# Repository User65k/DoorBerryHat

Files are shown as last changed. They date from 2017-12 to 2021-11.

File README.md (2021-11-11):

# DoorBerry
Use a Raspberry Pi as a VoIP door intercom system.

I use it with my FritzBox to alert all my DECT Phones.
Tested on a Pi 2B+ and a Pi Zero with raspbian (and mono).

## Software

Please find it [here](https://github.com/User65k/DoorBerryServer).

## Hardware

All Files are creaded with [KiCad](http://kicad.org/).

### Old Door system

The new System replaces the indoor part of a RITTO intercom system. The Door itself and the other appartments where not modified.

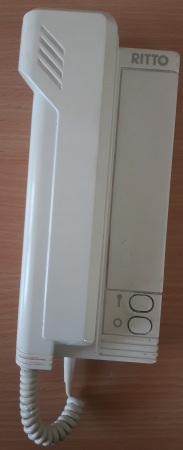
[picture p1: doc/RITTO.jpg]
RITO Door bell


The old system had a fairly simple circut:

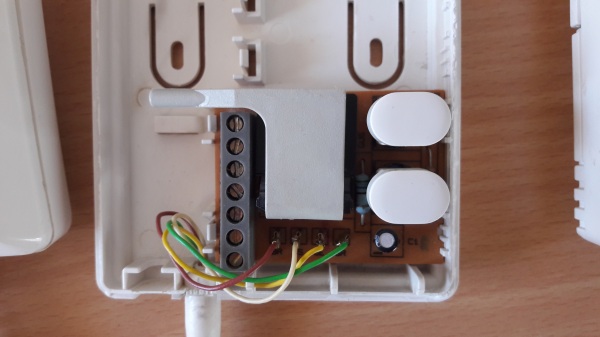
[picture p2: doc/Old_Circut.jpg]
RITO Inside


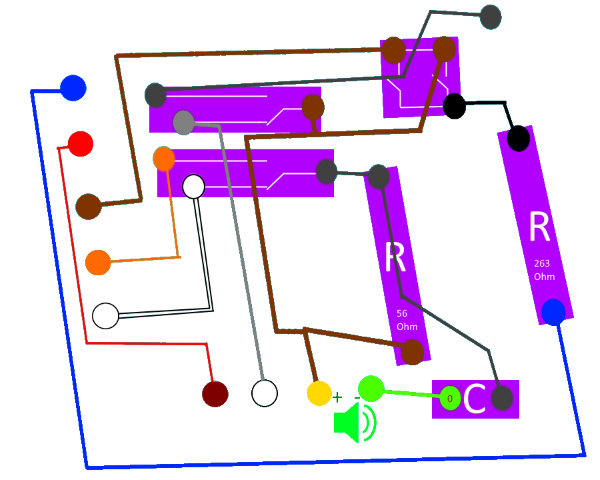
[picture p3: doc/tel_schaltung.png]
Circut


### New Door Intercom

The system is replaced by a Raspberry with a custum Hat (utilizing the GPIOs of the Pi).
Bell and Buzzer can operate independently from the new system (in case of Network errors, Bugs, :speak_no_evil:).

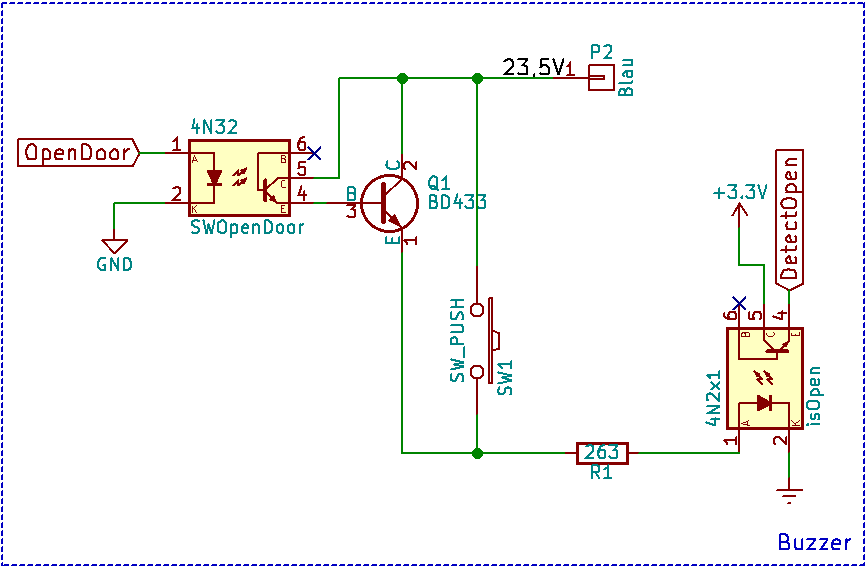
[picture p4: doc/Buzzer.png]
Hat Buzzer


The switch (SW1) can open the door regardless of any errors in the Pi.

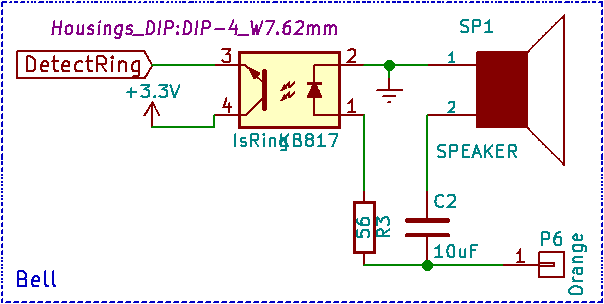
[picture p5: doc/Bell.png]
Hat Bell


The speaker (SP1) will notify about someone ringing the Bell independently from the Pi.

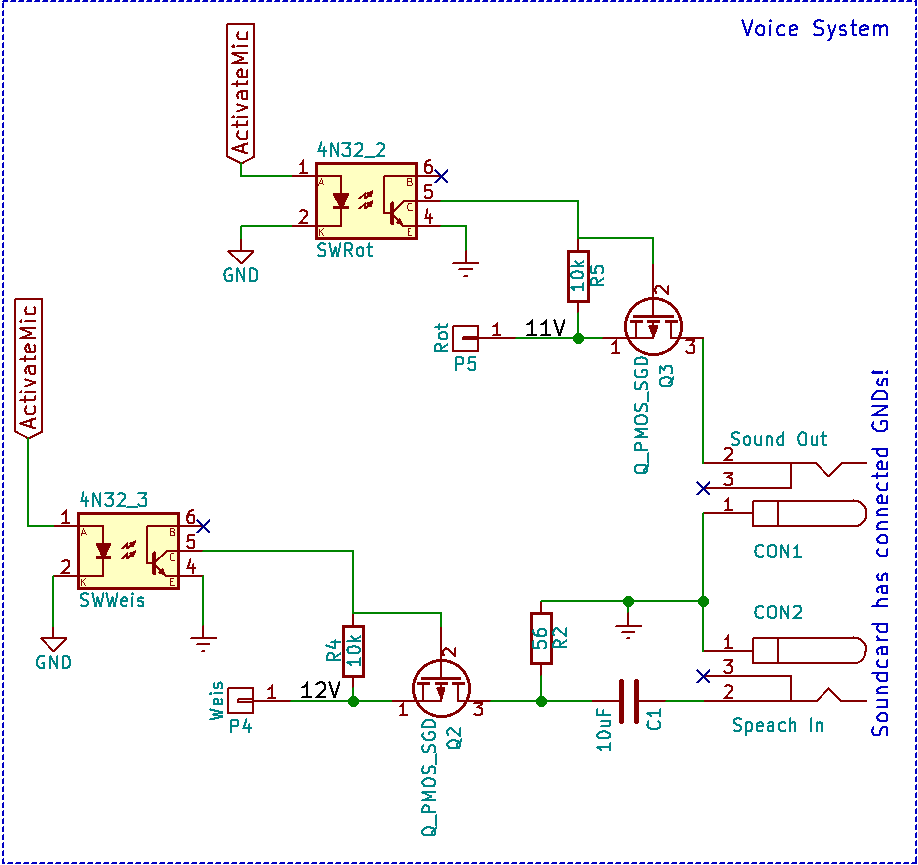
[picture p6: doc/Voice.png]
Hat Intercom


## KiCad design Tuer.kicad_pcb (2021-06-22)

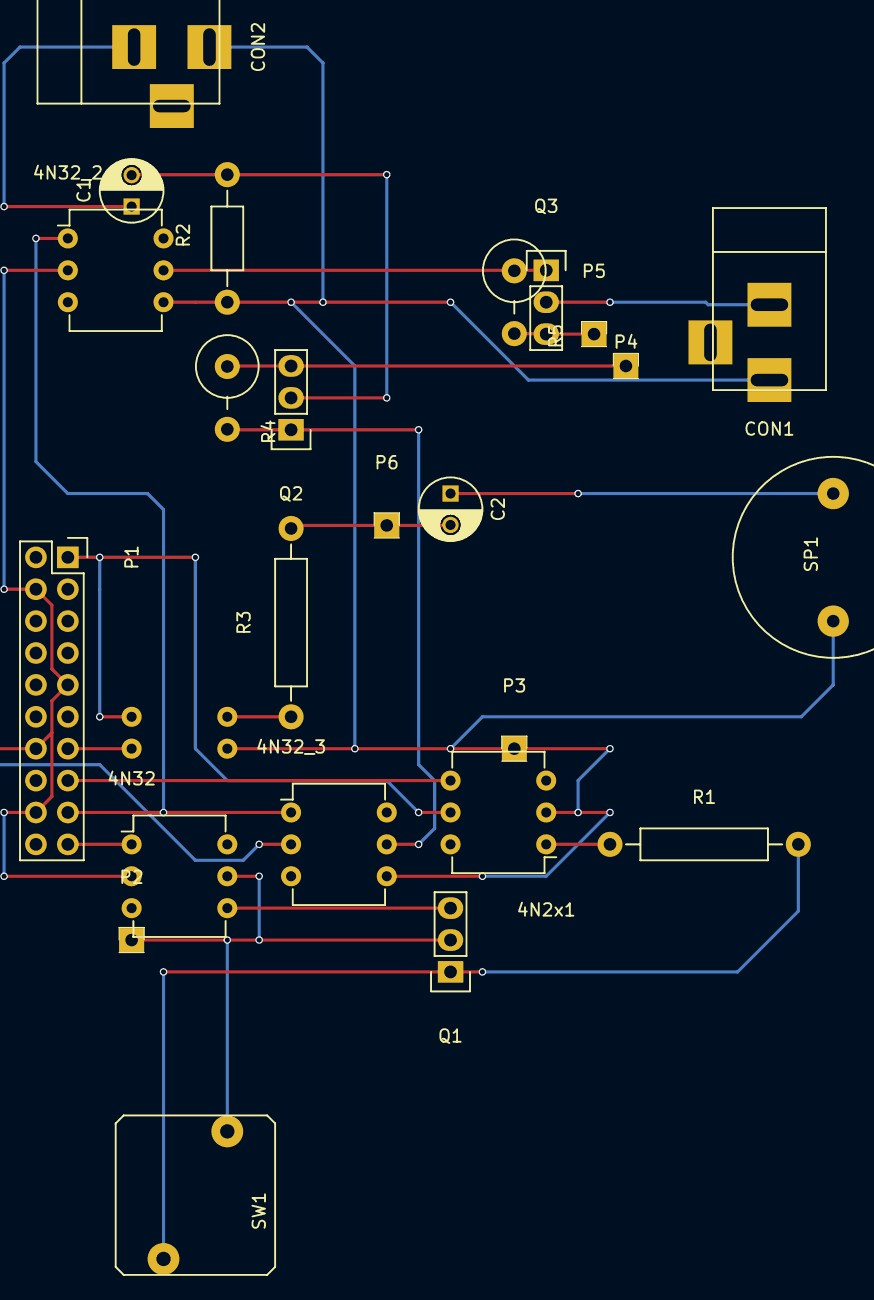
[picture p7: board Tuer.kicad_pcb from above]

Board: 2 copper layers, 25 parts (1 on the bottom side), 21 nets.

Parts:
4N2x1: isOpen; DIP-6_W7.62mm
4N32: SWOpenDoor; DIP-6_W7.62mm
4N32_2: SWRot; DIP-6_W7.62mm
4N32_3: SWWeis; DIP-6_W7.62mm
C1, C2: 10uF; C_Radial_D5_L6_P2.5
CON1: Sound Out; BARREL_JACK
CON2: Speach In; BARREL_JACK
KB817: IsRing; DIP-4_W7.62mm
P1: Rasp17_36; Socket_Strip_Straight_2x10
P2: Blau; Pin_Header_Straight_1x01
P3: Braun; Pin_Header_Straight_1x01
P4: Weis; Pin_Header_Straight_1x01
P5: Rot; Pin_Header_Straight_1x01
P6: Orange; Pin_Header_Straight_1x01
Q1: BD433; Pin_Header_Straight_1x03
Q2, Q3: Q_PMOS_GDS; Pin_Header_Straight_1x03
R1: 263; Resistor_Horizontal_RM15mm
R2: 56; Resistor_Horizontal_RM10mm
R3: 56; Resistor_Horizontal_RM15mm
R4, R5: 10k; Resistor_Vertical_RM5mm
SP1: SPEAKER; BUZZER
SW1: SW_PUSH

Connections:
+3V3: 4N2x1.5, KB817.4, P1.1
/11V: P5.1, Q3.3, R5.2
/12V: P4.1, Q2.3, R4.1
/23,5V: 4N32.5, P2.1, Q1.2, SW1.1
ActivateMic: 4N32_2.1, 4N32_3.1, P1.17
DetectOpen: 4N2x1.4, P1.15
DetectRing: KB817.3, P1.13
Earth: 4N2x1.2, 4N32_2.4, 4N32_3.4, CON1.1, CON2.1, KB817.2, P3.1, R2.1, SP1.1
GND: 4N32.2, 4N32_2.2, 4N32_3.2, P1.4, P1.9, P1.14, P1.18
unnamed: 4N2x1.1, R1.1
unnamed: 4N32.4, Q1.3
unnamed: 4N32_2.5, Q3.1, R5.1
unnamed: 4N32_3.5, Q2.1, R4.2
unnamed: C1.1, CON2.2
unnamed: C1.2, Q2.2, R2.2
unnamed: C2.1, SP1.2
unnamed: C2.2, P6.1, R3.2
unnamed: CON1.2, Q3.2
unnamed: KB817.1, R3.1
unnamed: Q1.1, R1.2, SW1.2
OpenDoor: 4N32.1, P1.19

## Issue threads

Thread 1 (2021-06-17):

Required libraries

kevin-fibich, 2021-06-17:
Openening this project in KiCad gives a lot of missing libraries. Can you add the reuired elements to the project or document which libraries should be installed?

User65k, 2021-06-21:
You are right! I found two *.lib files and uploaded them. KiCad now seems happy with it

kevin-fibich, 2021-06-21:
Hi,

my fresh KiCad 5.1.9 with digikey libs is still complaining a lot, here is what it thinks it is missing:

transistors.lib
conn.lib
linear.lib
regul.lib
cmos4000.lib
adc-dac.lib
memory.lib
xilinx.lib
microcontrollers.lib
dsp.lib
microchip.lib
analog_switches.lib
motorola.lib
texas.lib
intel.lib
digital-audio.lib
philips.lib
display.lib
cypress.lib
siliconi.lib
opto.lib
atmel.lib
contrib.lib
valves.lib

I also tried to downgrade to KiCad 4.0.7 which did complain a lot less but still has missing elements like 4N32_1-3, 4N2x1, P1 and more.

User65k, 2021-06-22:
Interesting - my local backup was different than github. I updated the files. Those should hopefully work (on KiCad 5.1.10)

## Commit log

2017-12-16 added circut
    [Tuer.kicad_pcb, Tuer.sch]
2021-06-22 hopfully fixed missing libs
    [Tuer.kicad_pcb, Tuer.sch]
2021-11-10 Update README.md
    https://forum.kicad.info/t/warning-avoid-all-links-to-kicad-pcb-org-use-kicad-org/31521
